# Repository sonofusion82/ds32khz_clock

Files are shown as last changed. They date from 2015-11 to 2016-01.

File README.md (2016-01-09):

Simple PICmicro-based digital clock with DS32KHZ TCXO
-----------------------------------------------------

When most normal people wants a table clock, they just buy one.
A simple clock from a "pasar malam" stall will cost about RM10.

But for some crazy people, they would rather spend RM50 and many hours over several weekends to build one!

As you may know, most digital clocks seems to drift up to 20 minutes per year.
Therefore, instead of using standard 32KHz "watch crystal", I've decided put a [DS32KHZ](https://www.maximintegrated.com/en/products/digital/clock-generation-distribution/silicon-crystal-oscillators/DS32KHZ.html) TCXO (temperature compensated crystal oscillator).

I've tried measuring the accuracy with an NTP synchronized Raspberry PI measuring a PPS signal from the PIC. 
It seems to be accurate to less than 1 second per week.
So, if the datasheet is correct, the it should be accurate with within 1 minute per year!

Here's the source code and the schematics open-sourced with MIT license.

It was created with MPLABX IDE and it can be compiled with both XC8 and SDCC compilers.
It has been tested with both PIC16F72 and PIC16F628A, other 28-pin PIC micros might work with some tweaking.

Some pictures:
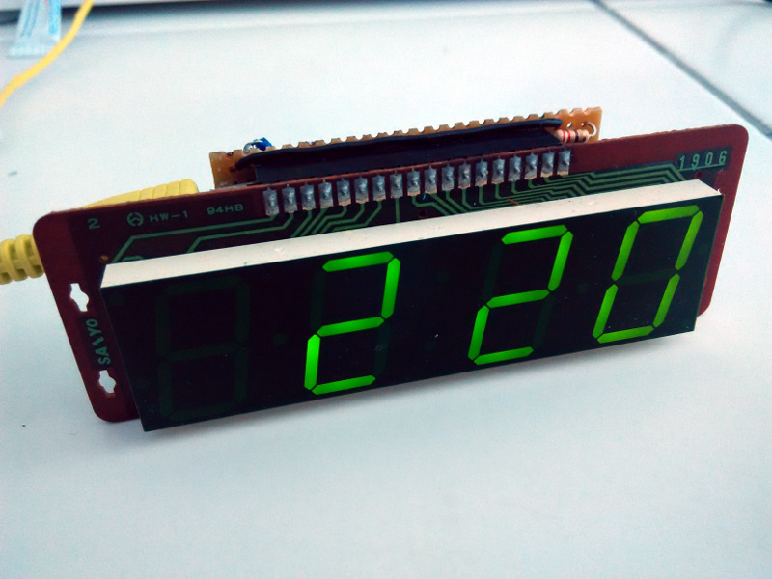
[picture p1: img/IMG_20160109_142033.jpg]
Final Final working clock


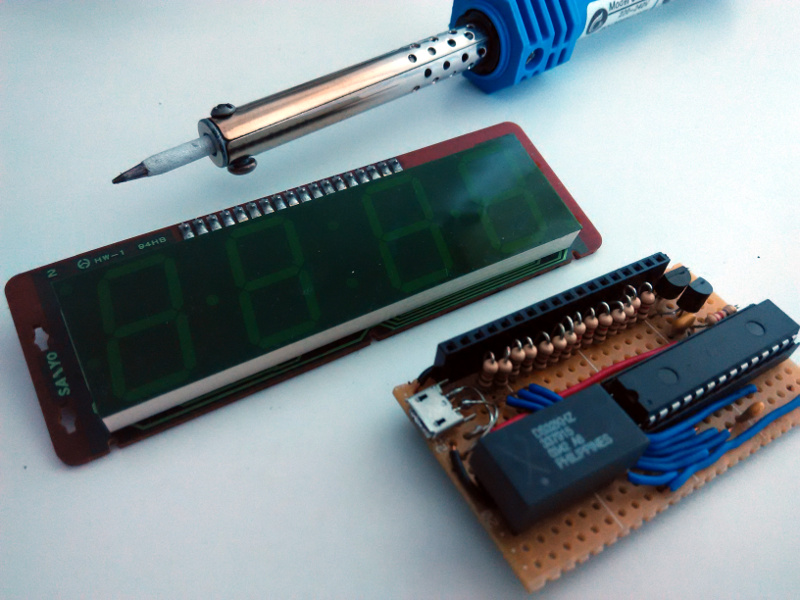
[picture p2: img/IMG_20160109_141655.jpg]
Before Assembling Open, before assembling


and schematic:

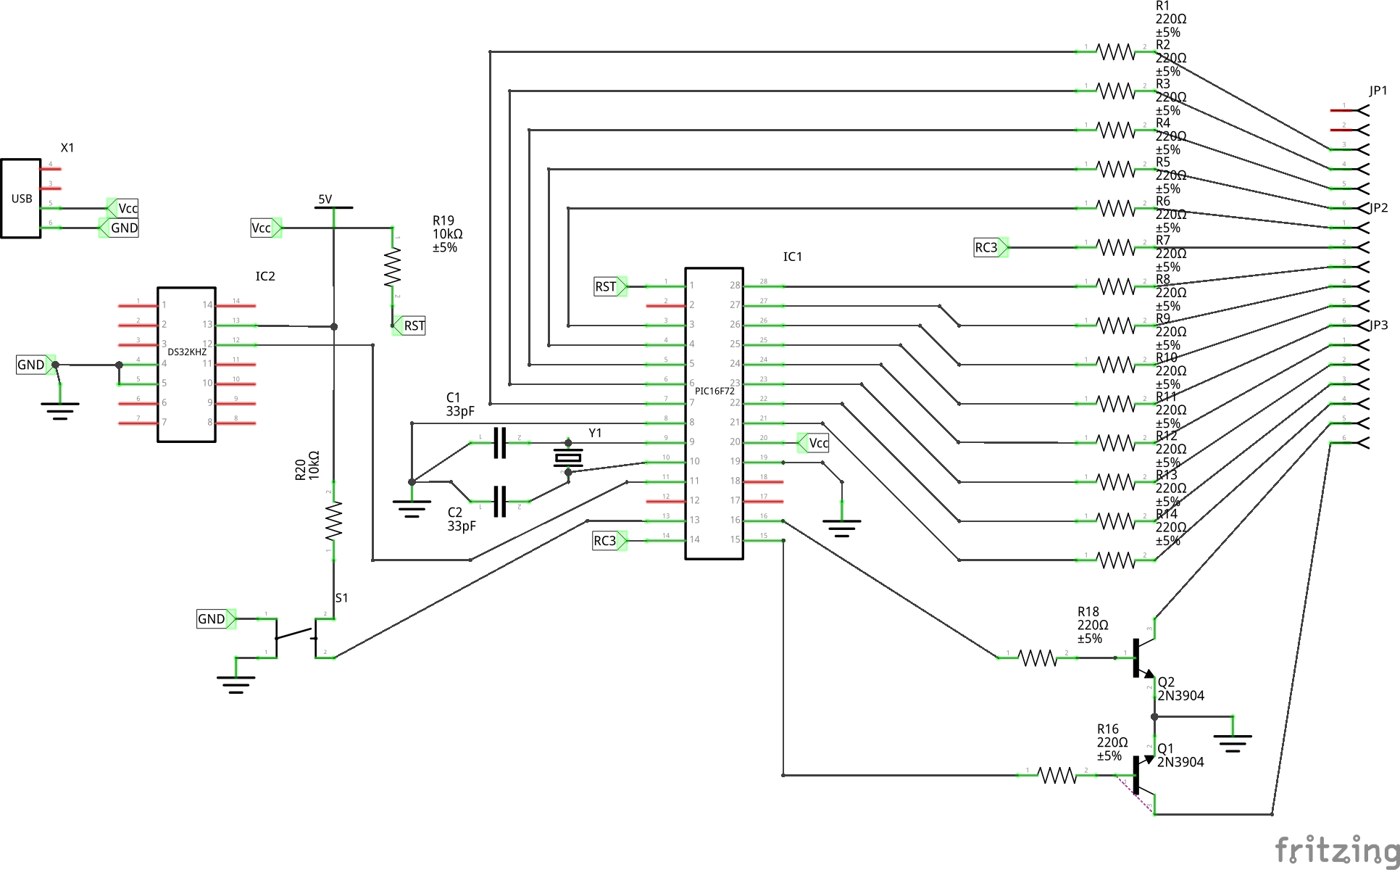
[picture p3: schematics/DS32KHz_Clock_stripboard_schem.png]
Schematics Open, before assembling


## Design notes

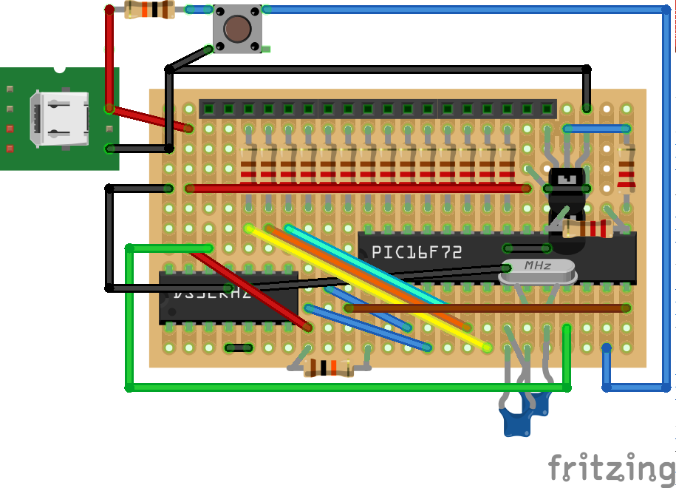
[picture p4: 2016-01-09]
schematics/DS32KHz_Clock_stripboard_bb.png

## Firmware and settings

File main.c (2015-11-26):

/* 
 * File:   main.c
 * Author: YewMing, Chen (fusion82@gmail.com)
 *
 * Created on September 20, 2015, 10:32 AM
 */

#ifdef __SDCC
#define NO_BIT_DEFINES
#include <pic16f72.h>
#else
//#define _XTAL_FREQ 20000000
#include <xc.h>
#endif

#include "current_timestamp.h"
#include "time_update.h"
#include "button_update.h"


#ifdef __SDCC

#ifdef __PIC16F876A_H__
static __code unsigned short __at (_CONFIG) config_word = \
    _FOSC_EXTRC & 
    _WDTE_ON & 
    _PWRTE_OFF & 
    _CP_OFF & 
    _BOREN_OFF & 
    _WRT_OFF & 
    _DEBUG_OFF & 
    _LVP_OFF;
#else
static __code unsigned short __at (_CONFIG) config_word = \
    _FOSC_RC & 
    _WDTE_ON & 
    _PWRTE_OFF & 
    _CP_OFF & 
    _BOREN_OFF;
#endif

#else // XC8 config

// #pragma config statements should precede project file includes.
// Use project enums instead of #define for ON and OFF.

#ifdef _PIC16F876A_H_
// CONFIG
#pragma config FOSC = EXTRC     // Oscillator Selection bits (RC oscillator) with 10Kohm and 22uF
//#pragma config FOSC = HS        // Oscillator Selection bits (HS oscillator)
#pragma config WDTE = ON       // Watchdog Timer Enable bit (WDT enabled)
#pragma config PWRTE = OFF       // Power-up Timer Enable bit (PWRT disabled)
#pragma config BOREN = OFF       // Brown-out Reset Enable bit (BOR disabled)
#pragma config LVP = OFF        // Low-Voltage (Single-Supply) In-Circuit Serial Programming Enable bit (RB3 is digital I/O, HV on MCLR must be used for programming))
#pragma config CPD = OFF        // Data EEPROM Memory Code Protection bit (Data EEPROM code protection off)
#pragma config WRT = OFF        // Flash Program Memory Write Enable bits (Write protection off; all program memory may be written to by EECON control)
#pragma config CP = OFF         // Flash Program Memory Code Protection bit (Code protection off)
#endif

#ifdef _PIC16F72_H_
// CONFIG
#pragma config FOSC = RC        // Oscillator Selection bits (RC oscillator)
#pragma config WDTE = ON        // Watchdog Timer Enable bit (WDT enabled)
#pragma config PWRTE = OFF      // Power-up Timer Enable bit (PWRT disabled)
#pragma config CP = OFF         // FLASH Program Memory Code Protection bit (Code protection off)
#pragma config BOREN = OFF       // Brown-out Reset Enable bit (BOR disabled)
#endif

#endif /* __SDCC */

/* CONSTANT TABLES */

/* BCD to IO mapping tables */

const unsigned char digit1[10][2] = {
    { 0b00011100, 0b00101100 },  /* 0 */
    { 0b00011000, 0b00000000 },  /* 1 */
    { 0b00010100, 0b00111000 },  /* 2 */
    { 0b00011100, 0b00011000 },  /* 3 */
    { 0b00011000, 0b00010100 },  /* 4 */
    { 0b00001100, 0b00011100 },  /* 5 */
    { 0b00001100, 0b00111100 },  /* 6 */
    { 0b00011100, 0b00000000 },  /* 7 */
    { 0b00011100, 0b00111100 },  /* 8 */
    { 0b00011100, 0b00011100 }   /* 9 */
};

/* digit 2 starts from bit 5 */
const unsigned char digit2[10][2] = {
    { 0b1011, 0b1110 }, /* 0 */
    { 0b0000, 0b0110 }, /* 1 */
    { 0b0111, 0b1100 }, /* 2 */
    { 0b0110, 0b1110 }, /* 3 */
    { 0b1100, 0b0110 }, /* 4 */
    { 0b1110, 0b1010 }, /* 5 */
    { 0b1111, 0b1010 }, /* 6 */
    { 0b0000, 0b1110 }, /* 7 */
    { 0b1111, 0b1110 }, /* 8 */
    { 0b1110, 0b1110 }  /* 9 */
};

const unsigned char digit3[10][2] = {
    { 0b01110, 0b10110 }, /* 0 */
    { 0b01100, 0b00000 }, /* 1 */
    { 0b01010, 0b11100 }, /* 2 */
    { 0b01110, 0b01100 }, /* 3 */
    { 0b01100, 0b01010 }, /* 4 */
    { 0b00110, 0b01110 }, /* 5 */
    { 0b00110, 0b11110 }, /* 6 */
    { 0b01110, 0b00000 }, /* 7 */
    { 0b01110, 0b11110 }, /* 8 */
    { 0b01110, 0b01110 }  /* 9 */
};


const unsigned char digit4[10][2] = {
    { 0b000000, 0b000000 }, /* 0 */
    { 0b110000, 0b000000 }, /* 1 */
    { 0b000000, 0b000000 }, /* 2 */
    { 0b000000, 0b000000 }, /* 3 */
    { 0b000000, 0b000000 }, /* 4 */
    { 0b000000, 0b000000 }, /* 5 */
    { 0b000000, 0b000000 }, /* 6 */
    { 0b000000, 0b000000 }, /* 7 */
    { 0b000000, 0b000000 }, /* 8 */
    { 0b000000, 0b000000 }  /* 9 */
};
 
/* GLOBAL VARIABLES */
volatile unsigned char tmr1_ticked = 0;
unsigned char display[4] = { 0 };
unsigned char display_ticked = 0;
unsigned char low_power_enable = 0;

#define TMR1H_RELOAD 0x80

#ifdef SDCC

// clear watchdog macro
#define CLRWDT()  __asm__( "clrwdt" );
// enable interrupt
#define ei()  (INTCONbits.GIE = 1)

static void interupt_service_routine (void) __interrupt 0
#else
void interrupt interupt_service_routine(void)
#endif
{
    /* only process timer-triggered interrupts */
    if(PIE1bits.TMR1IE && PIR1bits.TMR1IF)
    {
        TMR1H = TMR1H_RELOAD;
        PIR1bits.TMR1IF = 0;
        tmr1_ticked = 1;
    }
}

static void init()
{
    /* Initialize GPIOs */
    PORTB = 0;
    TRISB = 0;
    
    ADCON1 = 0x07; /* PCFG3:PCFG0 = 0111 => All Digital Ports */
#if defined(_PIC16F876A_H_) || defined(__PIC16F876A_H__)
    CMCON = 0x07;
#endif
    PORTA = 0;
    TRISA = 0;

    PORTC = 0;
    TRISC = 0b11000111;
    
    /* TIMER 1 setting
     * pre-scale 1:1
     * oscillator disable for DS32KHZ input
     * not sync to internal clock
     * external input
     * timer 1 on
     */
    T1CON = 0b000111;
    TMR1L = 0x00;
    TMR1H = TMR1H_RELOAD;
    PIE1bits.TMR1IE = 1;
    INTCONbits.PEIE = 1;
 
    ei();
}

#define GET_LOOP_TICK (TMR1L & 0xC0)


static void updateDisplayIOs(unsigned char toggle)
{
    PORTB  = digit1[display[3]][toggle];
    PORTB |= ((digit2[display[2]][toggle] & 0b111) << 5);
    
    PORTCbits.RC3 = (digit2[display[2]][toggle] & 0b1000) ? 1 : 0;
    
    PORTA  = digit3[display[1]][toggle];
    PORTA |= digit4[display[0]][toggle];
    
    /* Blink the center colon LEDs */
    PORTBbits.RB1 = (TMR1H & 0b01000000) ? 0 : 1;
}

static void display_update()
{
    static unsigned char loopTicks = 0;
    static unsigned char loopCount = 0;
    
    /* Display block */
    if (loopTicks != GET_LOOP_TICK)
    {
        loopCount++;
        loopTicks = GET_LOOP_TICK;

        if ((loopCount & 3) == 0)
        {
            PORTCbits.RC4 = 0;

            updateDisplayIOs(1);

            PORTCbits.RC5 = 1;
            
            display_ticked = 1;
        }
        else if ((loopCount & 3) == 2)
        {
            PORTCbits.RC5 = 0;

            updateDisplayIOs(0);

            PORTCbits.RC4 = 1;
            
            display_ticked = 1;
        }
        else if (low_power_enable)
        {
            PORTCbits.RC4 = 0;
            PORTCbits.RC5 = 0;
            PORTB = 0;
            PORTA = 0;
            PORTCbits.RC3 = 0;
        }
        
    }
}

/* Main program loop
 * 
 */
void main()
{
    init();
    
    hours   = (BUILD_TIME_SINCE_MIDNIGHT / 3600L);
    minutes = (BUILD_TIME_SINCE_MIDNIGHT % 3600L) / 60;
    seconds = (BUILD_TIME_SINCE_MIDNIGHT % 60);
    
    while (1)
    {
        display_update();
        
        switch (button_update(!PORTCbits.RC2))
        {
            // BUTTON_1 adds 1 minute
            case BUTTON_1:
                incrementMinute();
                seconds = 0;
                tmr1_ticked = 1; // force a time update
                break;

            // BUTTON_2 adds 1 hour
            case BUTTON_2:
                incrementHour();
                seconds = 0;
                tmr1_ticked = 1; // force a time update
                break;
                
            case BUTTON_NONE:
            default:
                break;
        }
        
        time_update(display);
        
        CLRWDT();
    }
   
    return;
}

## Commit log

2015-09-20 SLEEP and wait for interupt
    Set timer to not synchronize with internal clock and use sleep to wait for interrupt
2015-10-10 Change to 20MHz crystal oscillator
    [main.c]
2015-10-10 Add UART driver (57600 bps)
2015-10-10 Fix UART buffer overflow
    [main.c]
2015-10-11 Improve common cathode switching
2015-11-09 Simplify and remove UART
    - Remove UART codes
    - Disable TMR1 oscillator for DS32KHZ
    - Switch back to EXTRC oscillator
    [main.c]
2015-11-11 Add volatile and fix int16 overflow
    [main.c]
2015-11-14 Fix low powe mode
    [main.c]
2015-11-14 Fix refactoring and optimize
    Remove division and fix static/global variables
    [main.c]
2015-11-14 Add button press control
2015-11-14 Button: Add more test case and update main.c
2015-11-15 Fix MPLABX project and add static to functions
    [main.c]
2015-11-26 Add button long press
2016-01-09 Add README and schematics
    [DS32KHz_Clock_stripboard.fzz]
